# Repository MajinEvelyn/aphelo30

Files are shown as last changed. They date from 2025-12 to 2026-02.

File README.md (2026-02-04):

# aphelo30

desk pic 1
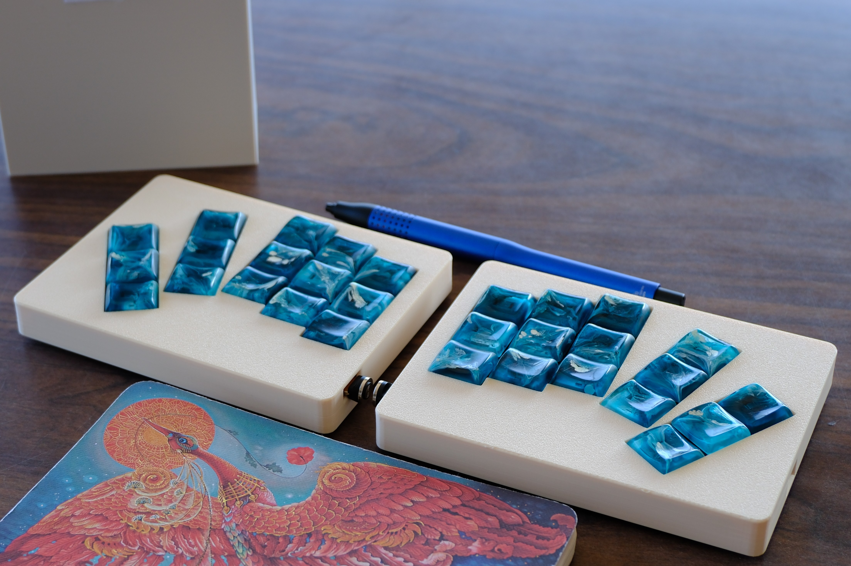
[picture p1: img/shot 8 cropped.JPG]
desk pic 2


Pictured with Chicago Steno keycaps by [Asymplex](https://www.asymplex.xyz/), case printed in Cream PETG-HF.

## Design Parameters
- Full split
- ZMK powered BLE wireless
- Nice! Nano v2 controlled
- Reversible PCB
- 30 keys in 3x5 configuration
- Choc v1 Switches with hotswap sockets
- No thumb keys
- Aggressive splay

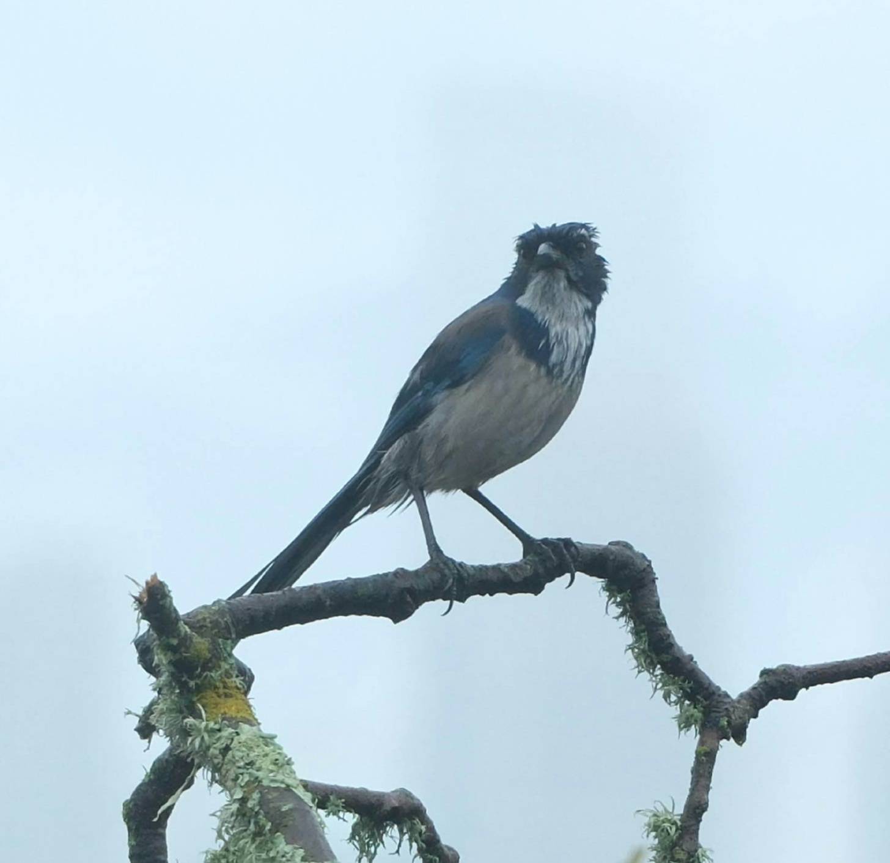
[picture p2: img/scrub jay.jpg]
scrub jay


Named for the *Aphelocoma* genus of scrub jay birds. 

## Overview

This weird combination of features is designed for my hands, which no currently existing boards accommodate. I have RSI issues in both of my thumbs, to the point that even single thumb key layouts don't work for me. Aside from this, the aggressive splay and finger positions were made with Ergopad, and recreated in Ergogen. 

In this repo you will find all files related to the design process, including the Ergogen config, KiCAD PCB files, related Gerbers, and case 3d files for printing. Unfortunately, I was only able to get the PCB to a 115x85mm footprint with this splay, so a little outside of the <100x100mm discount size for JLCPCB. Despite this and the expensive microcontroller, you should be able to build this board for somewhere between 80-120$.

## Case

There are 4 bosses for heat set inserts on the underside of each half's top case. Press them into each boss with a soldering iron, and use your M2 screws through the holes in the bottom case to screw into the heat set inserts.
There are heat set insert soldering tips available for pretty cheap to make this process easy, but I've heard this is easy enough with typical soldering iron tips.

bottom case

## Carrying Case

I designed this to slide in both halves vertically, with the USB ports facing up and open air to protect the keycaps. It is not fully enclosed because for my use case I am placing it in a bag. I glued some felt to the bottom of the case to cushion it, and ribbons to make pulling the keeb halves out easy.

carry case

## Firmware
ZMK: https://github.com/MajinEvelyn/zmk-config-aphelo30

## BOM

| Name | Count | Notes |
| ---- | ----- | --- |
| PCB | 2 | These are reversible, so either PCB works with either half. |
| Nice! Nano v2 MCU | 2 | |
| Choc v1 Switches | 30 | |
| Choc v1 Hotswap Sockets | 30 | |
| Choc v1 Keycaps | 30 | |
| Power Switch | 2 | |
| Reset Switch | 2 | You can omit these if you are fine with using ZMK reset behavior or shorting RST pins to reflash firmware. |
| 110mah LiPo Battery | 2 | There is plenty of space for other batteries inside the case, but I have not tested others. |
| Bumpons | 8 | Size is up to your preference. |
| M2(x8mm) Screws | 8 | Countersunk screws are best, they will seat perfectly into the chamfered holes in the bottom case. |
| M2 Heat Set Inserts | 8 | |

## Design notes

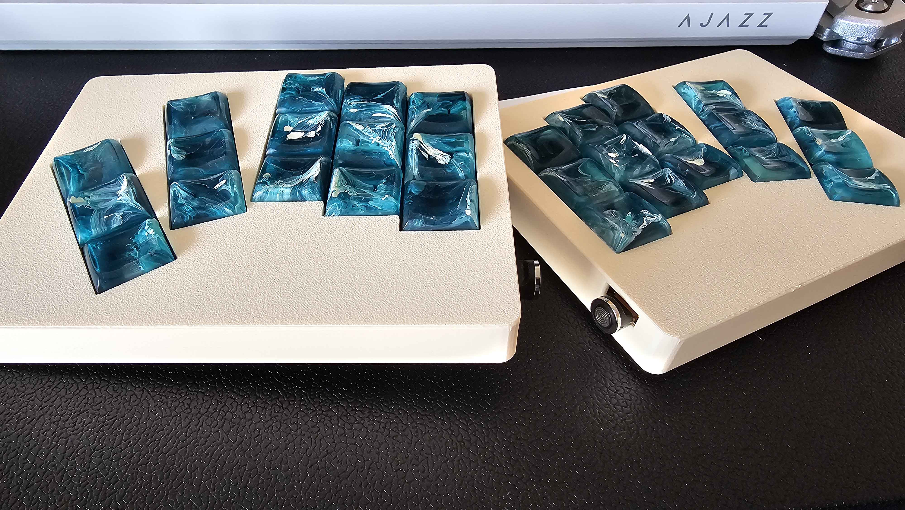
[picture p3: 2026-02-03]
img/aphelo desk.jpg

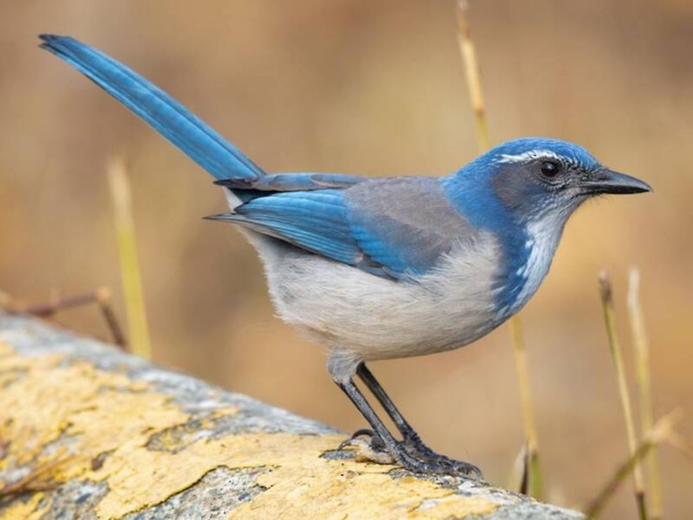
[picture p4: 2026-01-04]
img/california scrub jay.jpg

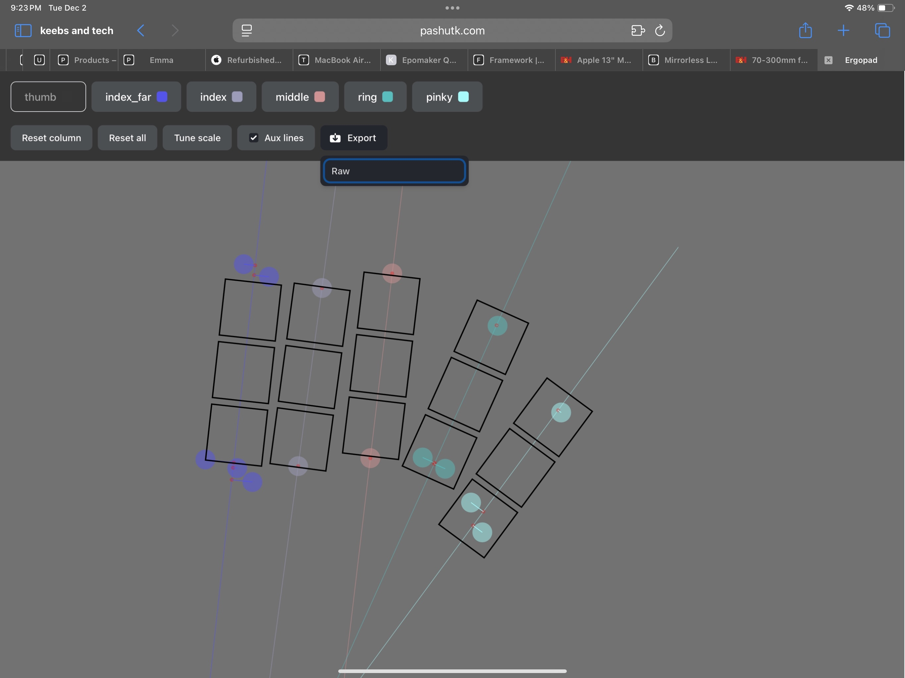
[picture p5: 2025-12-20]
img/ergopad righ.png

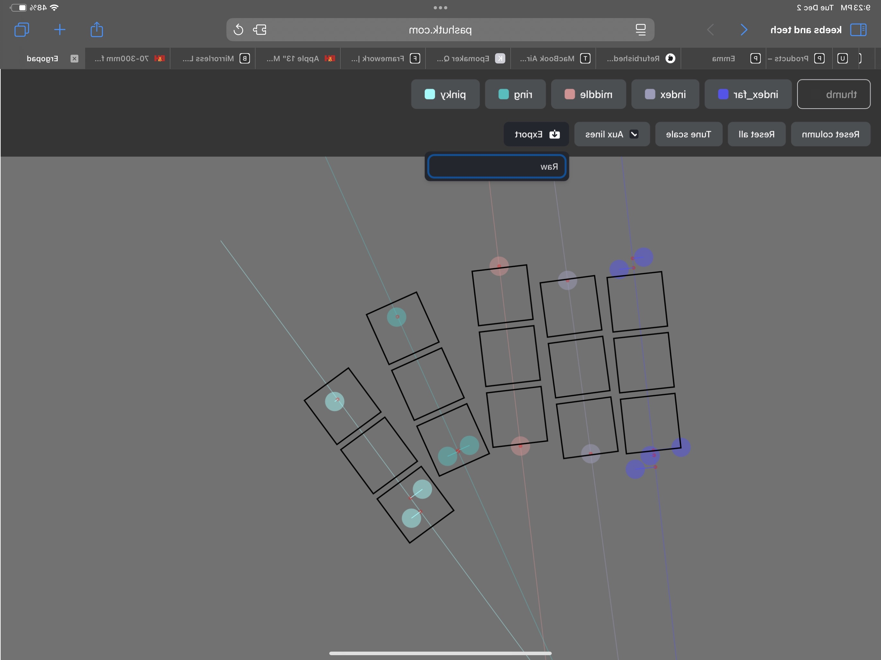
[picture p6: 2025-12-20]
img/ergopad left.png

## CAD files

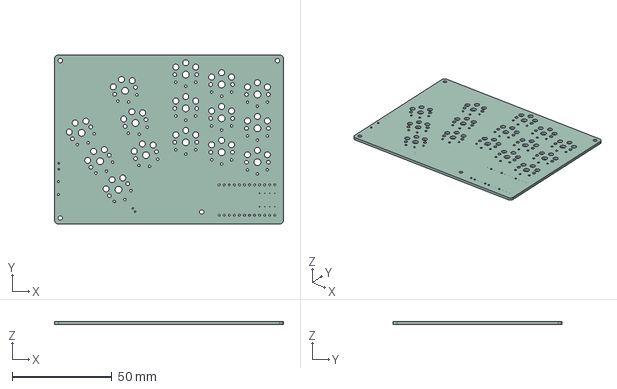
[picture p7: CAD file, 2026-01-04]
aphelo30/aphelo30.step
115.0 x 85.0 x 1.51 mm

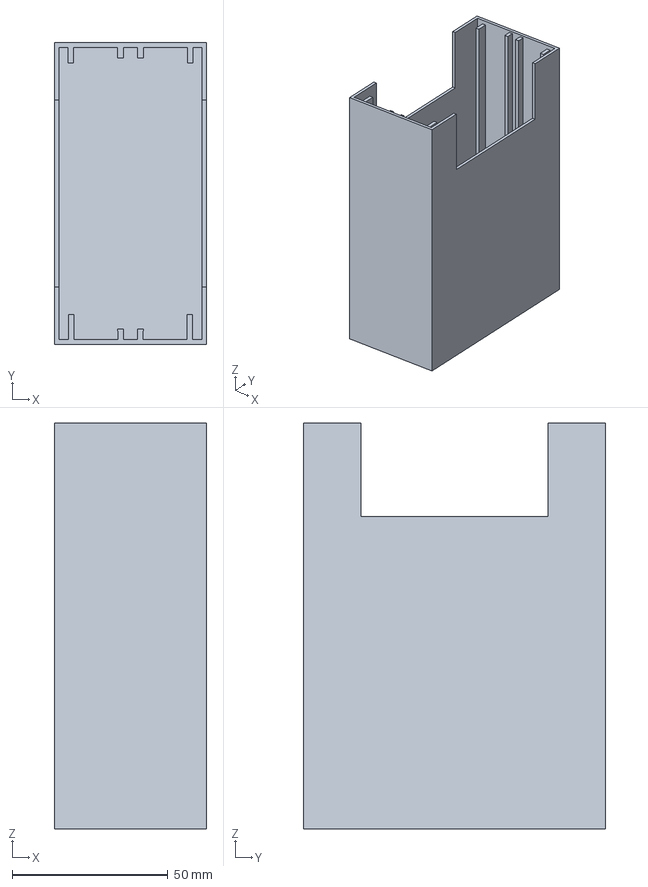
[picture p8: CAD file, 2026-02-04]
case/Aphelo30 carrying case.3mf
49.0 x 97.0 x 130.5 mm

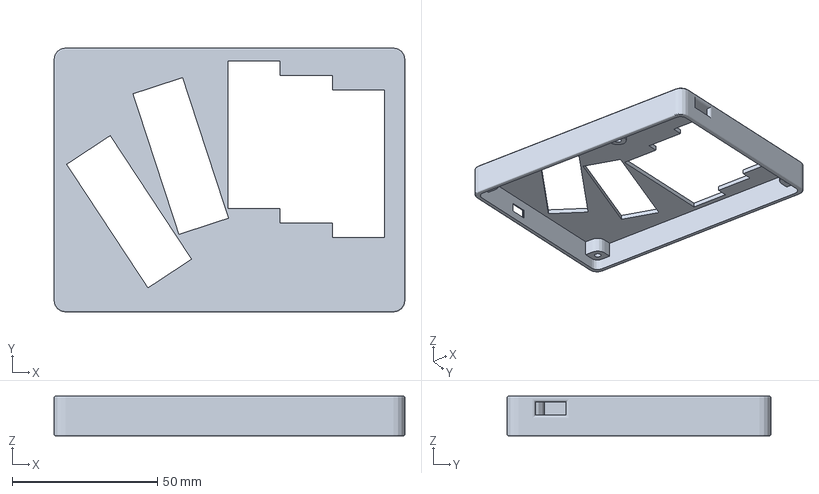
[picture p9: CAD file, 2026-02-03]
case/Aphelo30 case top 1.5.3mf
121.0 x 91.0 x 13.7 mm

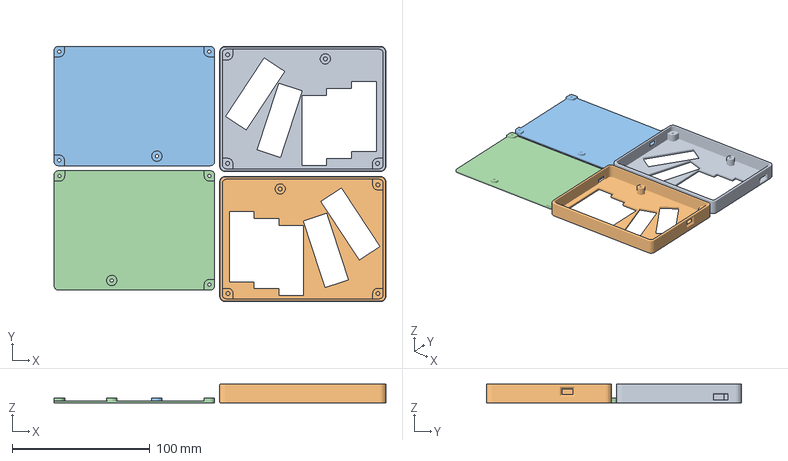
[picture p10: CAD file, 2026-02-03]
case/Aphelo30 case bottom 1.5.3mf
241.4 x 185.6 x 13.7 mm
walls_+_top_cover x 2
bottom_cover x 2

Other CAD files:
aphelo30/aphelo30.stl

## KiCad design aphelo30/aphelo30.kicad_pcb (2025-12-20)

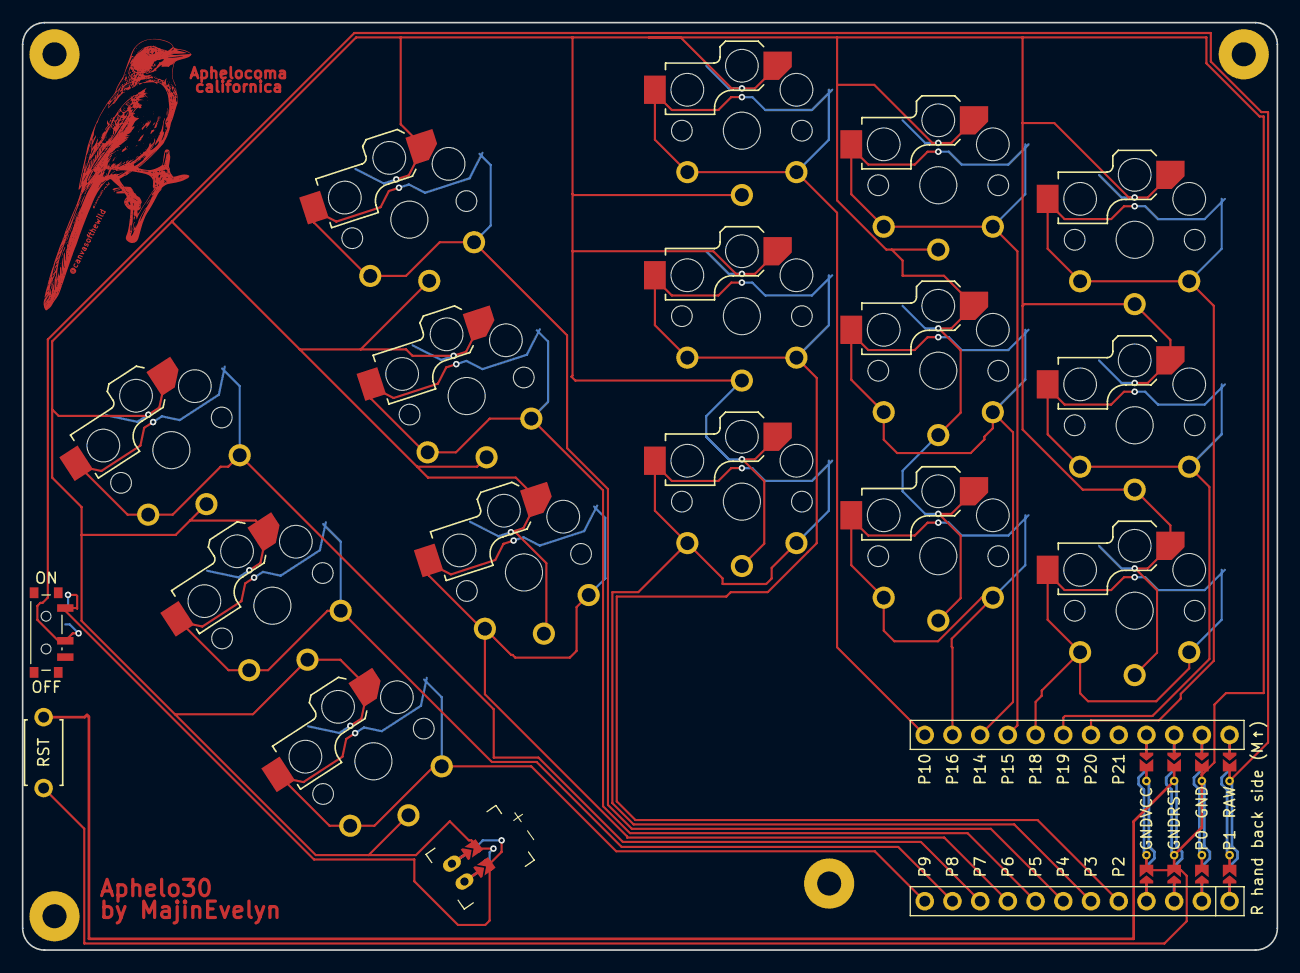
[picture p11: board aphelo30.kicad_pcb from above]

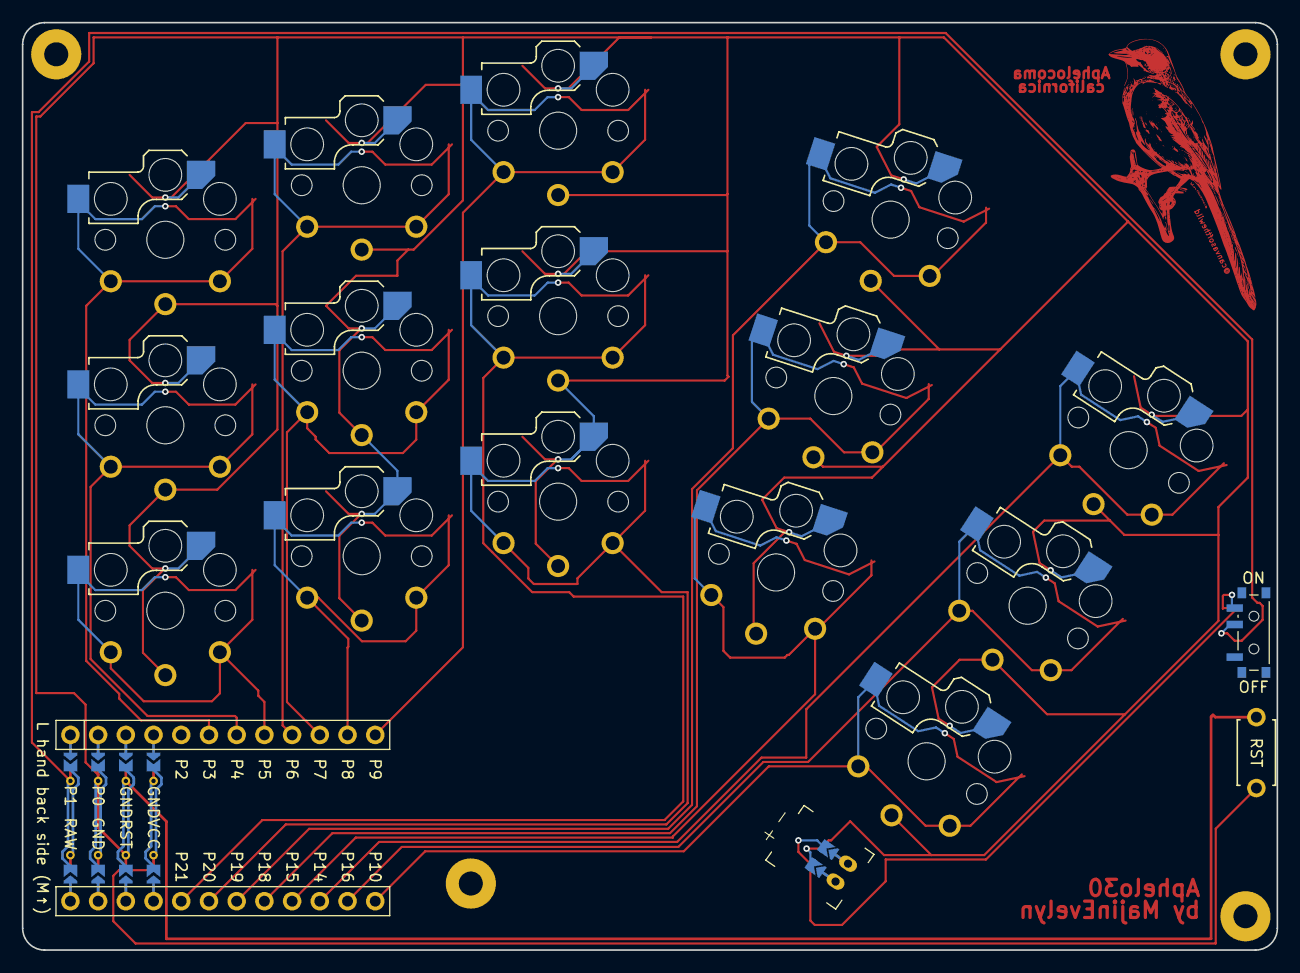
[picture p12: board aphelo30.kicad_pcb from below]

Board: 2 copper layers, 115.0 x 85.0 mm, 23 parts (15 on the bottom side), 21 nets.

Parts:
JST1: battery_connector_jst_ph_2
MCU1: mcu_nice_nano
MH1, MH2, MH3, MH4: mounting_hole_npth
PWR1: power_switch_smd_side
RST1: reset_switch_tht_top
S1, S2, S3, S4, S5, S6, S7, S8, S9, S10, S11, S12, S13, S14, S15: switch_choc_v1_v2

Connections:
BAT_P: JST1.1, PWR1.1, PWR1.3
GND: JST1.2, MCU1.103, MCU1.104, MCU1.123, RST1.2, S1.1, S1.2, S2.1, S2.2, S3.1, S3.2, S4.1, S4.2, S5.1, S5.2, S6.1, S6.2, S7.1, S7.2, S8.1, S8.2, S9.1, S9.2, S10.1, S10.2, S11.1, S11.2, S12.1, S12.2, S13.1, S13.2, S14.1, S14.2, S15.1, S15.2
JST1_1: JST1.11, JST1.21, JST1.31
JST1_2: JST1.12, JST1.22, JST1.32
P2: MCU1.5, S8.1, S8.2
P3: MCU1.6, S7.1, S7.2
P4: MCU1.7, S6.1, S6.2
P5: MCU1.8, S5.1, S5.2
P6: MCU1.9, S4.1, S4.2
P7: MCU1.10, S3.1, S3.2
P8: MCU1.11, S2.1, S2.2
P9: MCU1.12, S1.1, S1.2
P10: MCU1.13, S9.1, S9.2
P14: MCU1.15, S11.1, S11.2
P15: MCU1.16, S12.1, S12.2
P16: MCU1.14, S10.1, S10.2
P18: MCU1.17, S13.1, S13.2
P19: MCU1.18, S14.1, S14.2
P20: MCU1.19, S15.1, S15.2
RAW: MCU1.124, PWR1.2
RST: MCU1.122, RST1.1

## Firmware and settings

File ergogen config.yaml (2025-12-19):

meta:
  engine: 4.1.0
units:
  px: cx + 2
  py: cy + 2
  $default_width: 18
  $default_height: 17
points:
  zones:
    matrix:
      anchor:
        shift: [100, -100]
      key:
        padding: 1cy
        spread: 1cx
      columns:
        pinky:
          key:
            splay: 33
          rows:
            top:
              column_net: P9
            home:
              column_net: P8
            bottom:
              column_net: P7
        ring:
          key:
            stagger: 7
            splay: -15
            spread: 21
          rows:
            top:
              column_net: P6
            home:
              column_net: P5
            bottom:
              column_net: P4
        middle:
          key:
            stagger: 0
            splay: -18
            spread: 21
          rows:
            top:
              column_net: P3
            home:
              column_net: P2
            bottom:
              column_net: P10
        index:
          key:
            stagger: -5
            splay: 0
          rows:
            top:
              column_net: P16
            home:
              column_net: P14
            bottom:
              column_net: P15
        inner:
          key:
            stagger: -5
          rows:
            top:
              column_net: P18
            home:
              column_net: P19
            bottom:
              column_net: P20
      rows:
        top:
        home:
        bottom:
outlines:
  bweh:
    - what: rectangle
      size: [cx, cy]
      where: true
  bloc:
    - what: rectangle
      operation: stack
      size: [113, 82]
      adjust.shift: [1.1 sx, -0.9 sy]
      fillet: 2
  combo:
    - name: bloc
    - operation: subtract
      name: bweh
pcbs:
  aphelo30:
    template: kicad8
    outlines:
      main:
        outline: bloc
    footprints:
      choc_hotswap:
        what: ceoloide/switch_choc_v1_v2
        where: true
        params:
          from: GND
          to: "{{column_net}}"
          include_corner_marks: true
          include_keycap: true
          keycap_height: 16.5
          keycap_width: 17.5
          reversible: true
          solder: true
          hotswap: true
          choc_v2_support: false
          outer_pad_width_front: 2.0
          outer_pad_width_back: 2.0
      mcu:
        what: ceoloide/mcu_nice_nano
        where:
          ref: matrix_inner_bottom
        params:
          reversible: true
          only_required_jumpers: true
        adjust:
          shift: [-6, -53]
          rotate: -90
      on_off_switch:
        what: ceoloide/power_switch_smd_side
        where: matrix_middle_top
        params:
          from: BAT_P
          to: RAW
          reversible: true
        adjust:
          shift: [-64.5, -12]
          rotate: 180
      reset_switch:
        what: ceoloide/reset_switch_tht_top
        where: matrix_middle_top
        params:
          reversible: true
        adjust:
          shift: [-64, -23]
          rotate: 90
      battery_connector:
        what: ceoloide/battery_connector_jst_ph_2
        where: matrix_middle_bottom
        params:
          reversible: true
        adjust:
          shift: [-26,-68]
          rotate: 125
      m2_screw_1:
        what: ceoloide/mounting_hole_npth
        where: 
          ref: matrix_middle_top
        adjust:
          shift: [-63,-35]
        params:
          hole_size: 4.6
          hole_drill: 2.2
      m2_screw_2:
        what: ceoloide/mounting_hole_npth
        where: 
          ref: matrix_middle_top
        adjust:
          shift: [-63,40]
        params:
          hole_size: 4.6
          hole_drill: 2.2
      m2_screw_3:
        what: ceoloide/mounting_hole_npth
        where: 
          ref: matrix_middle_top
        adjust:
          shift: [44,40]
        params:
          hole_size: 4.6
          hole_drill: 2.2
      m2_screw_4:
        what: ceoloide/mounting_hole_npth
        where: 
          ref: matrix_middle_top
        adjust:
          shift: [8,-35]
        params:
          hole_size: 4.6
          hole_drill: 2.2
cases:

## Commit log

2026-02-03 Rename Aphelo30 case bottom 1.5.3mf to case/Aphelo30 case bottom 1.5.3mf
    [Aphelo30 case bottom 1.5.3mf]
2026-02-03 Enhance BOM section with additional notes
    Added additional notes for PCB, Reset Switch, LiPo Battery, Bumpons, and M2 Screws in the BOM section.
2026-02-04 Update README with keycaps and case information
    Added details about keycaps and case material.
